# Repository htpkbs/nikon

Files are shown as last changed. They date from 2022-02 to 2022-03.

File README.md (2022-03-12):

# Overview

The nikon is a keyboard PCB.

It has:

* A column-staggered, ortholinear layout
* Low profile Kailh Choc switch spacing
* A split design
* Thumb key clusters
* USB-C
* Symmetry (the same PCB can be used for both left and right halves)

# v1.0 Notes

Capacitors `C1` and `C4` are mislabeled! The silkscreen labels are swapped.

# Key Layout

The key layout looks like this:

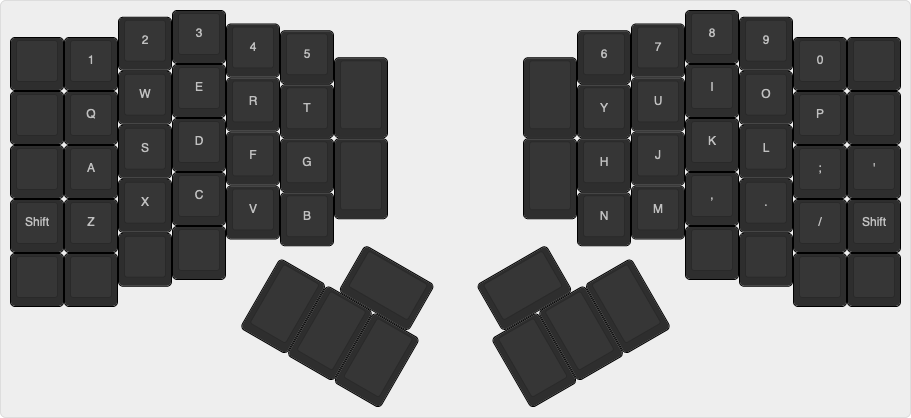
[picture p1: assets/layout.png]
Key layout


This is the raw data that can be pasted into [Keyboard Layout Editor](http://www.keyboard-layout-editor.com/):

```
[{x:3,c:"#2e2e2e",t:"#9c9c9c",a:7},"3",{x:8.5},"8"],
[{y:-0.875,x:2},"2",{x:10.5},"9"],
[{y:-0.875,x:4},"4",{x:6.5},"7"],
[{y:-0.875,x:5},"5",{x:4.5},"6"],
[{y:-0.875},"","1",{x:12.5},"0",""],
[{y:-0.625,x:6,h:1.5},"",{x:2.5,h:1.5},""],
[{y:-0.875,x:3},"E",{x:8.5},"I"],
[{y:-0.875,x:2},"W",{x:10.5},"O"],
[{y:-0.875,x:4},"R",{x:6.5},"U"],
[{y:-0.875,x:5},"T",{x:4.5},"Y"],
[{y:-0.875},"","Q",{x:12.5},"P",""],
[{y:-0.5,x:3},"D",{x:8.5},"K"],
[{y:-0.875,x:2},"S",{x:10.5},"L"],
[{y:-0.875,x:4},"F",{x:6.5},"J"],
[{y:-0.875,x:5},"G",{h:1.5},"",{x:2.5,h:1.5},"","H"],
[{y:-0.875},"","A",{x:12.5},";","'"],
[{y:-0.5,x:3},"C",{x:8.5},","],
[{y:-0.875,x:2},"X",{x:10.5},"."],
[{y:-0.875,x:4},"V",{x:6.5},"M"],
[{y:-0.875,x:5},"B",{x:4.5},"N"],
[{y:-0.875},"Shift","Z",{x:12.5},"/","Shift"],
[{y:-0.375,x:2},"",{x:10.5},""],
[{y:-0.625},"","",{x:12.5},"",""],
[{rx:7.5,ry:4,x:-4.5},""],
[{rx:9,x:3.5},""],
[{r:30,rx:7.5,y:0.75,x:-0.625,w:1.5},""],
[{x:-1.875,h:1.5},"",{h:1.5},"",{h:1.5},""],
[{r:-30,rx:9,y:0.75,x:-0.875,w:1.5},""],
[{x:-1.125,h:1.5},"",{h:1.5},"",{h:1.5},""]
```

# PCB Renders

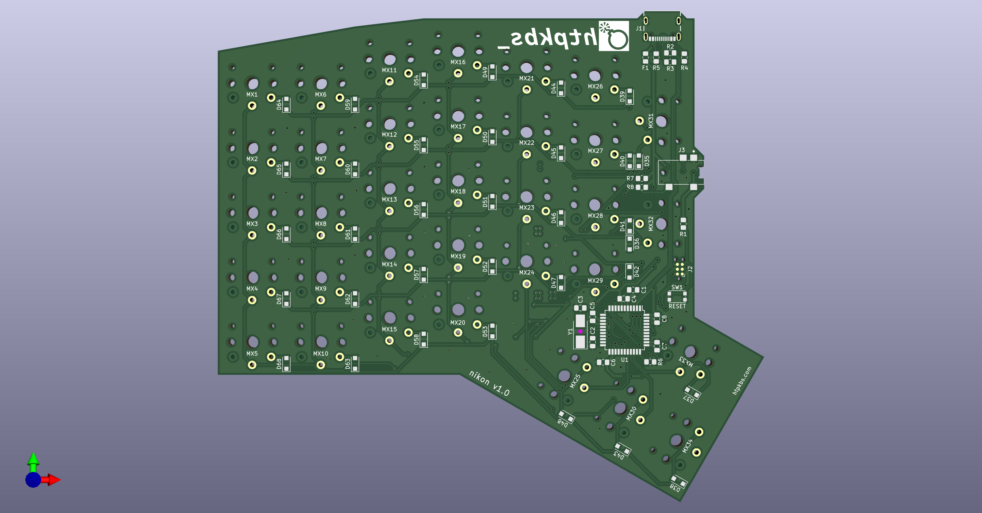
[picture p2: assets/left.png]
Left PCB front


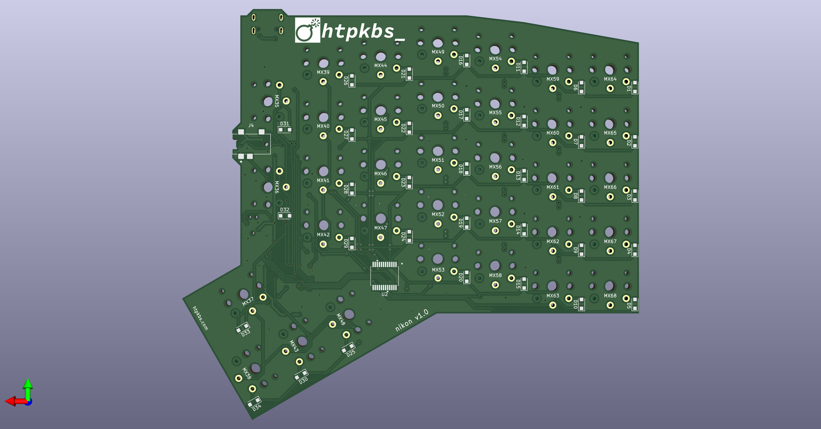
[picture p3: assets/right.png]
Right PCB front


# Case

Files are in the `case` directory.

# Schematic

[There is a PDF of the schematic here](assets/schematic.pdf).

# AVR Programming

To-do.

## QMK

The nikon uses a port expander (the ATmega MCP23018), similar to the ErgoDox. The firmware will likely be copied from the [Pterodactyl keyboard](https://github.com/qmk/qmk_firmware/tree/master/keyboards/handwired/pterodactyl) since that seems to be the most recent keyboard with a custom `matrix.c` and support for a port expander. Eventually hopefully there will be a [generalized matrix.c for keyboards that use I/O expanders](https://github.com/qmk/qmk_firmware/issues/2065).

# Sublicenses

* The Kailh Choc switch footprints are from the [keyswitch-kicad-libary repository](https://github.com/perigoso/keyswitch-kicad-library). [The CC BY 4.0 license is included here](LICENSE.keyswitch-kicad-library).
* The keyswitch symbols are modified versions from the [MX_Alps_Hybrid repository](https://github.com/ai03-2725/MX_Alps_Hybrid). [The MIT license is included here](LICENSE.MX_Alps_Hybrid).
* The TRRS jack symbol and footprint are not licensed by CUI Devices and are free to use.
* The USB jack symbol and footprint are from SnapEDA (linked from the GCT website) and do not appear to be licensed by GCT.
* The MCP23018 symbol and footprint are from Microchip and are subject to the Ultra Library terms and conditions, which state, "You may incorporate the CONTENT that you are authorized to access into your products or designs which may be distributed without restriction, including for commercial, educational, and open-source purposes."

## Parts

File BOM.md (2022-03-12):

# Bill of Materials

J2 (the Tag-Connect ISP headers) and MX1-MX68 (the key switches) are not included.

Since the PCB is reversible, the BOM is split up between the left and right halves. To build a full keyboard, you need the components for both halves.

## Left Half

| Reference | Quantity | Value | Link |
| --- | --- | --- | --- |
| D1-D34 | 34 | 1N4148 | https://www.digikey.com/en/products/detail/taiwan-semiconductor-corporation/1N4148W-RHG/7357065 |
| J4 | 1 | SJ2-35954-SMT-TR | https://www.digikey.com/en/products/detail/cui-devices/SJ2-35954A-SMT-TR/6619576 |
| U2 | 1 | MCP23018-E/SS | https://www.digikey.com/en/products/detail/microchip-technology/MCP23018-E-SS/1999506 |

## Right Half

| Reference | Quantity | Value | Link |
| --- | --- | --- | --- |
| C1 | 1 | 1u | https://www.digikey.com/en/products/detail/avx-corporation/0805DC105KAT2A/11245462 |
| C2, C3 | 2 | 22pF | https://www.digikey.com/en/products/detail/avx-corporation/08055C220JAT2A/1602912 |
| C4 | 1 | 4.7u | https://www.digikey.com/en/products/detail/avx-corporation/08056D475KAT2A/563526 |
| C5-C8 | 4 | 0.1u | https://www.digikey.com/en/products/detail/avx-corporation/08053D104KAT2A/2345252 |
| D35-D68 | 34 | 1N4148 | https://www.digikey.com/en/products/detail/taiwan-semiconductor-corporation/1N4148W-RHG/7357065
| F1 | 1 | 100mA | https://www.digikey.com/en/products/detail/littelfuse-inc/0805L020YR/1212820 |
| J1 | 1 | USB4105-GF-A | https://www.digikey.com/en/products/detail/gct/USB4105-GF-A/11198441 |
| J3 | 1 | SJ2-35954-SMT-TR | https://www.digikey.com/en/products/detail/cui-devices/SJ2-35954A-SMT-TR/6619576 |
| R1, R6 | 2 | 10k | https://www.digikey.com/en/products/detail/bourns-inc/CR0805-FX-1002ELF/3593209 |
| R2, R3 | 2 | 22R | https://www.digikey.com/en/products/detail/bourns-inc/CR0805-FX-22R0ELF/3784764 |
| R4, R5 | 2 | 5.1k | https://www.digikey.com/en/products/detail/bourns-inc/CR0805-FX-5101ELF/3784995 |
| R7, R8 | 2 | 4.7k | https://www.digikey.com/en/products/detail/bourns-inc/CR0805-FX-4701ELF/3784970 |
| SW1 | 1 | Reset | https://www.digikey.com/en/products/detail/c-k/KMR241NG-LFS/2176486 |
| U1 | 1 | ATmega32U4-AU | https://www.digikey.com/en/products/detail/microchip-technology/ATMEGA32U4-AU/1914602 |
| Y1 | 1 | 16MHz | https://www.digikey.com/en/products/detail/abracon-llc/ABM3-16-000MHZ-B2-T/675298 |

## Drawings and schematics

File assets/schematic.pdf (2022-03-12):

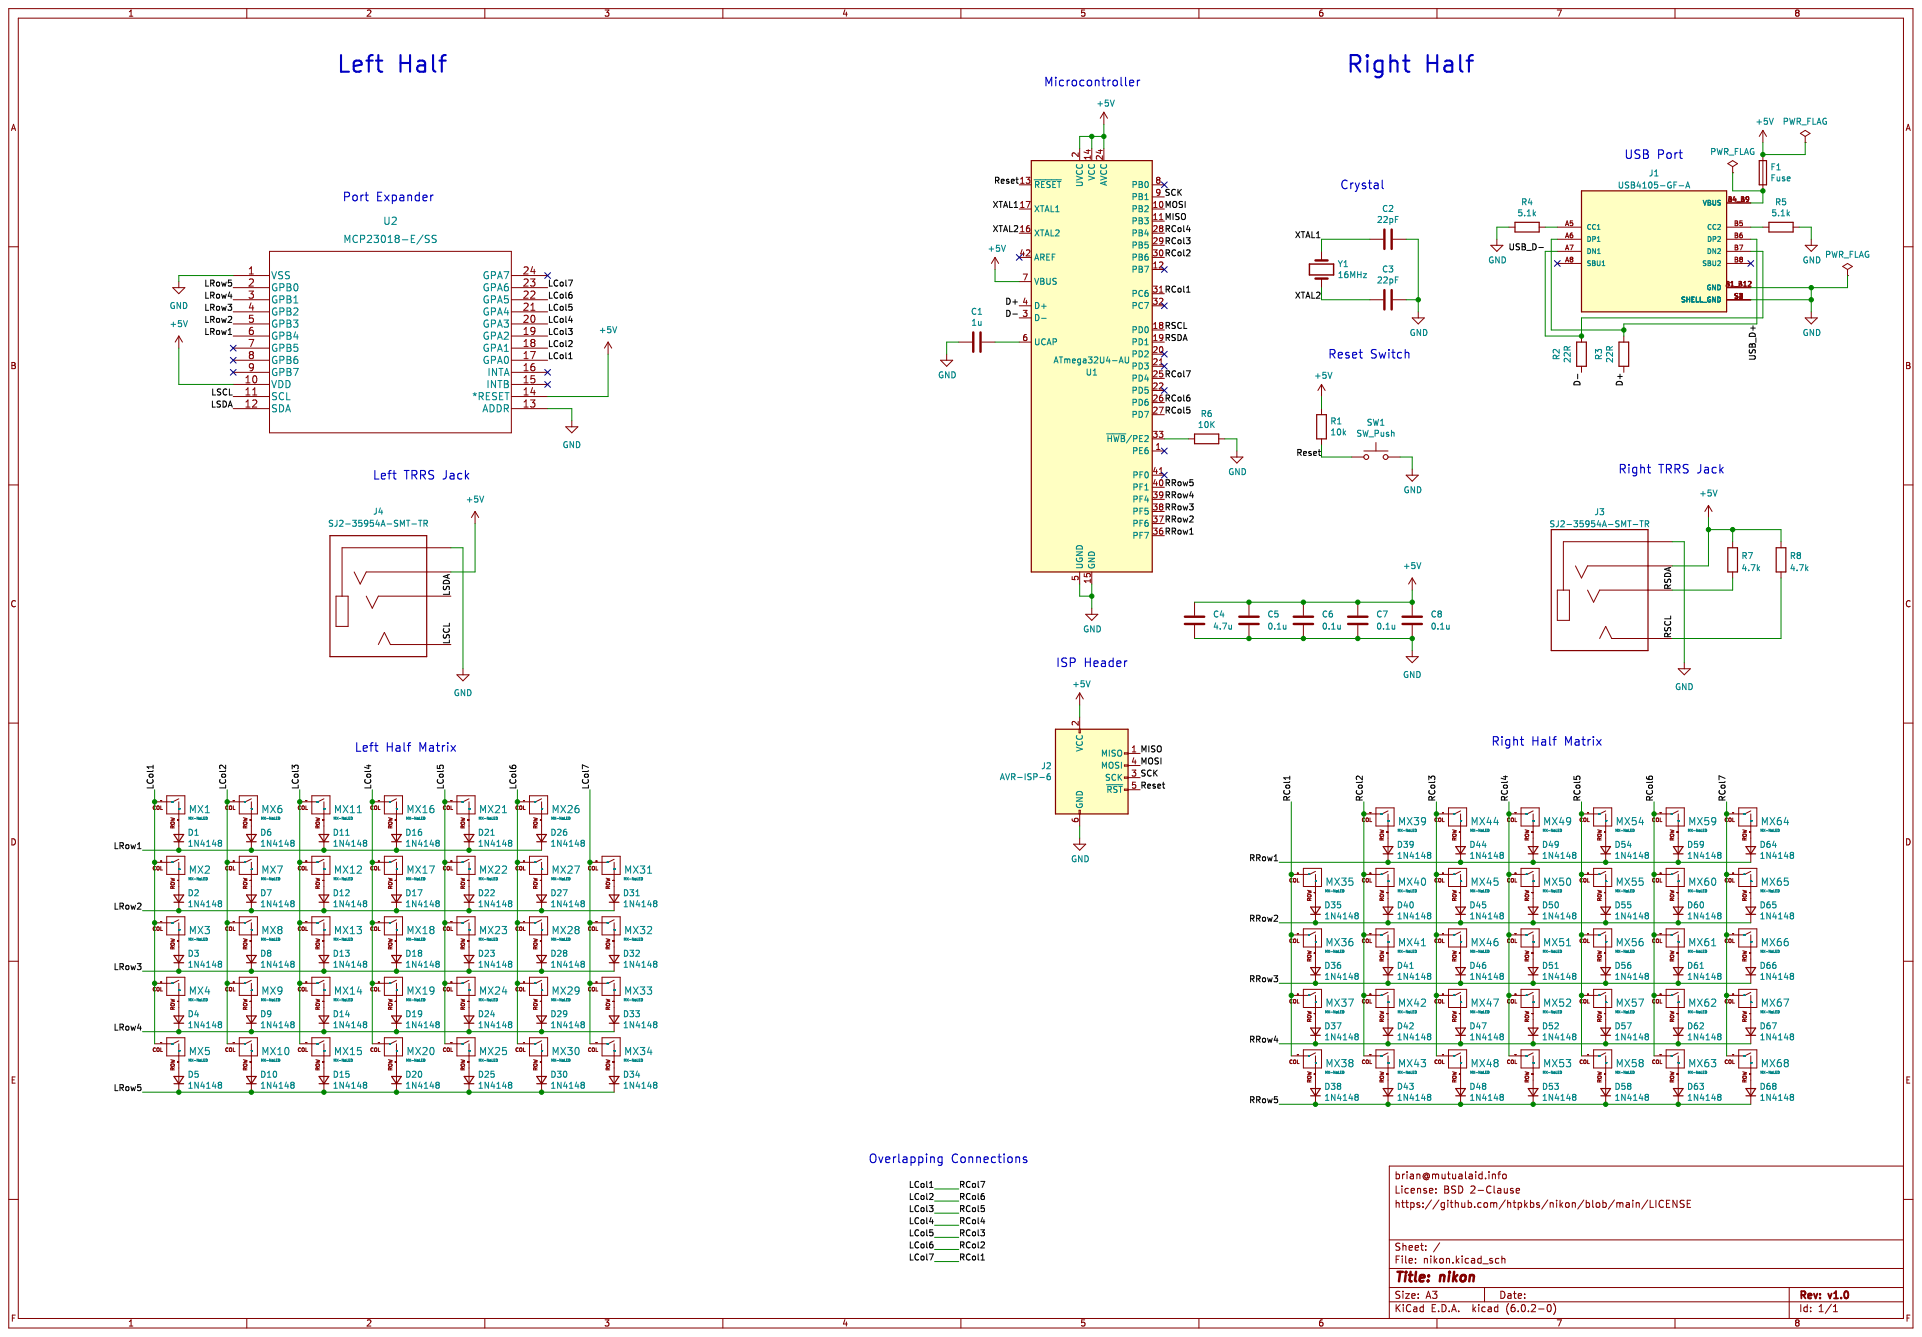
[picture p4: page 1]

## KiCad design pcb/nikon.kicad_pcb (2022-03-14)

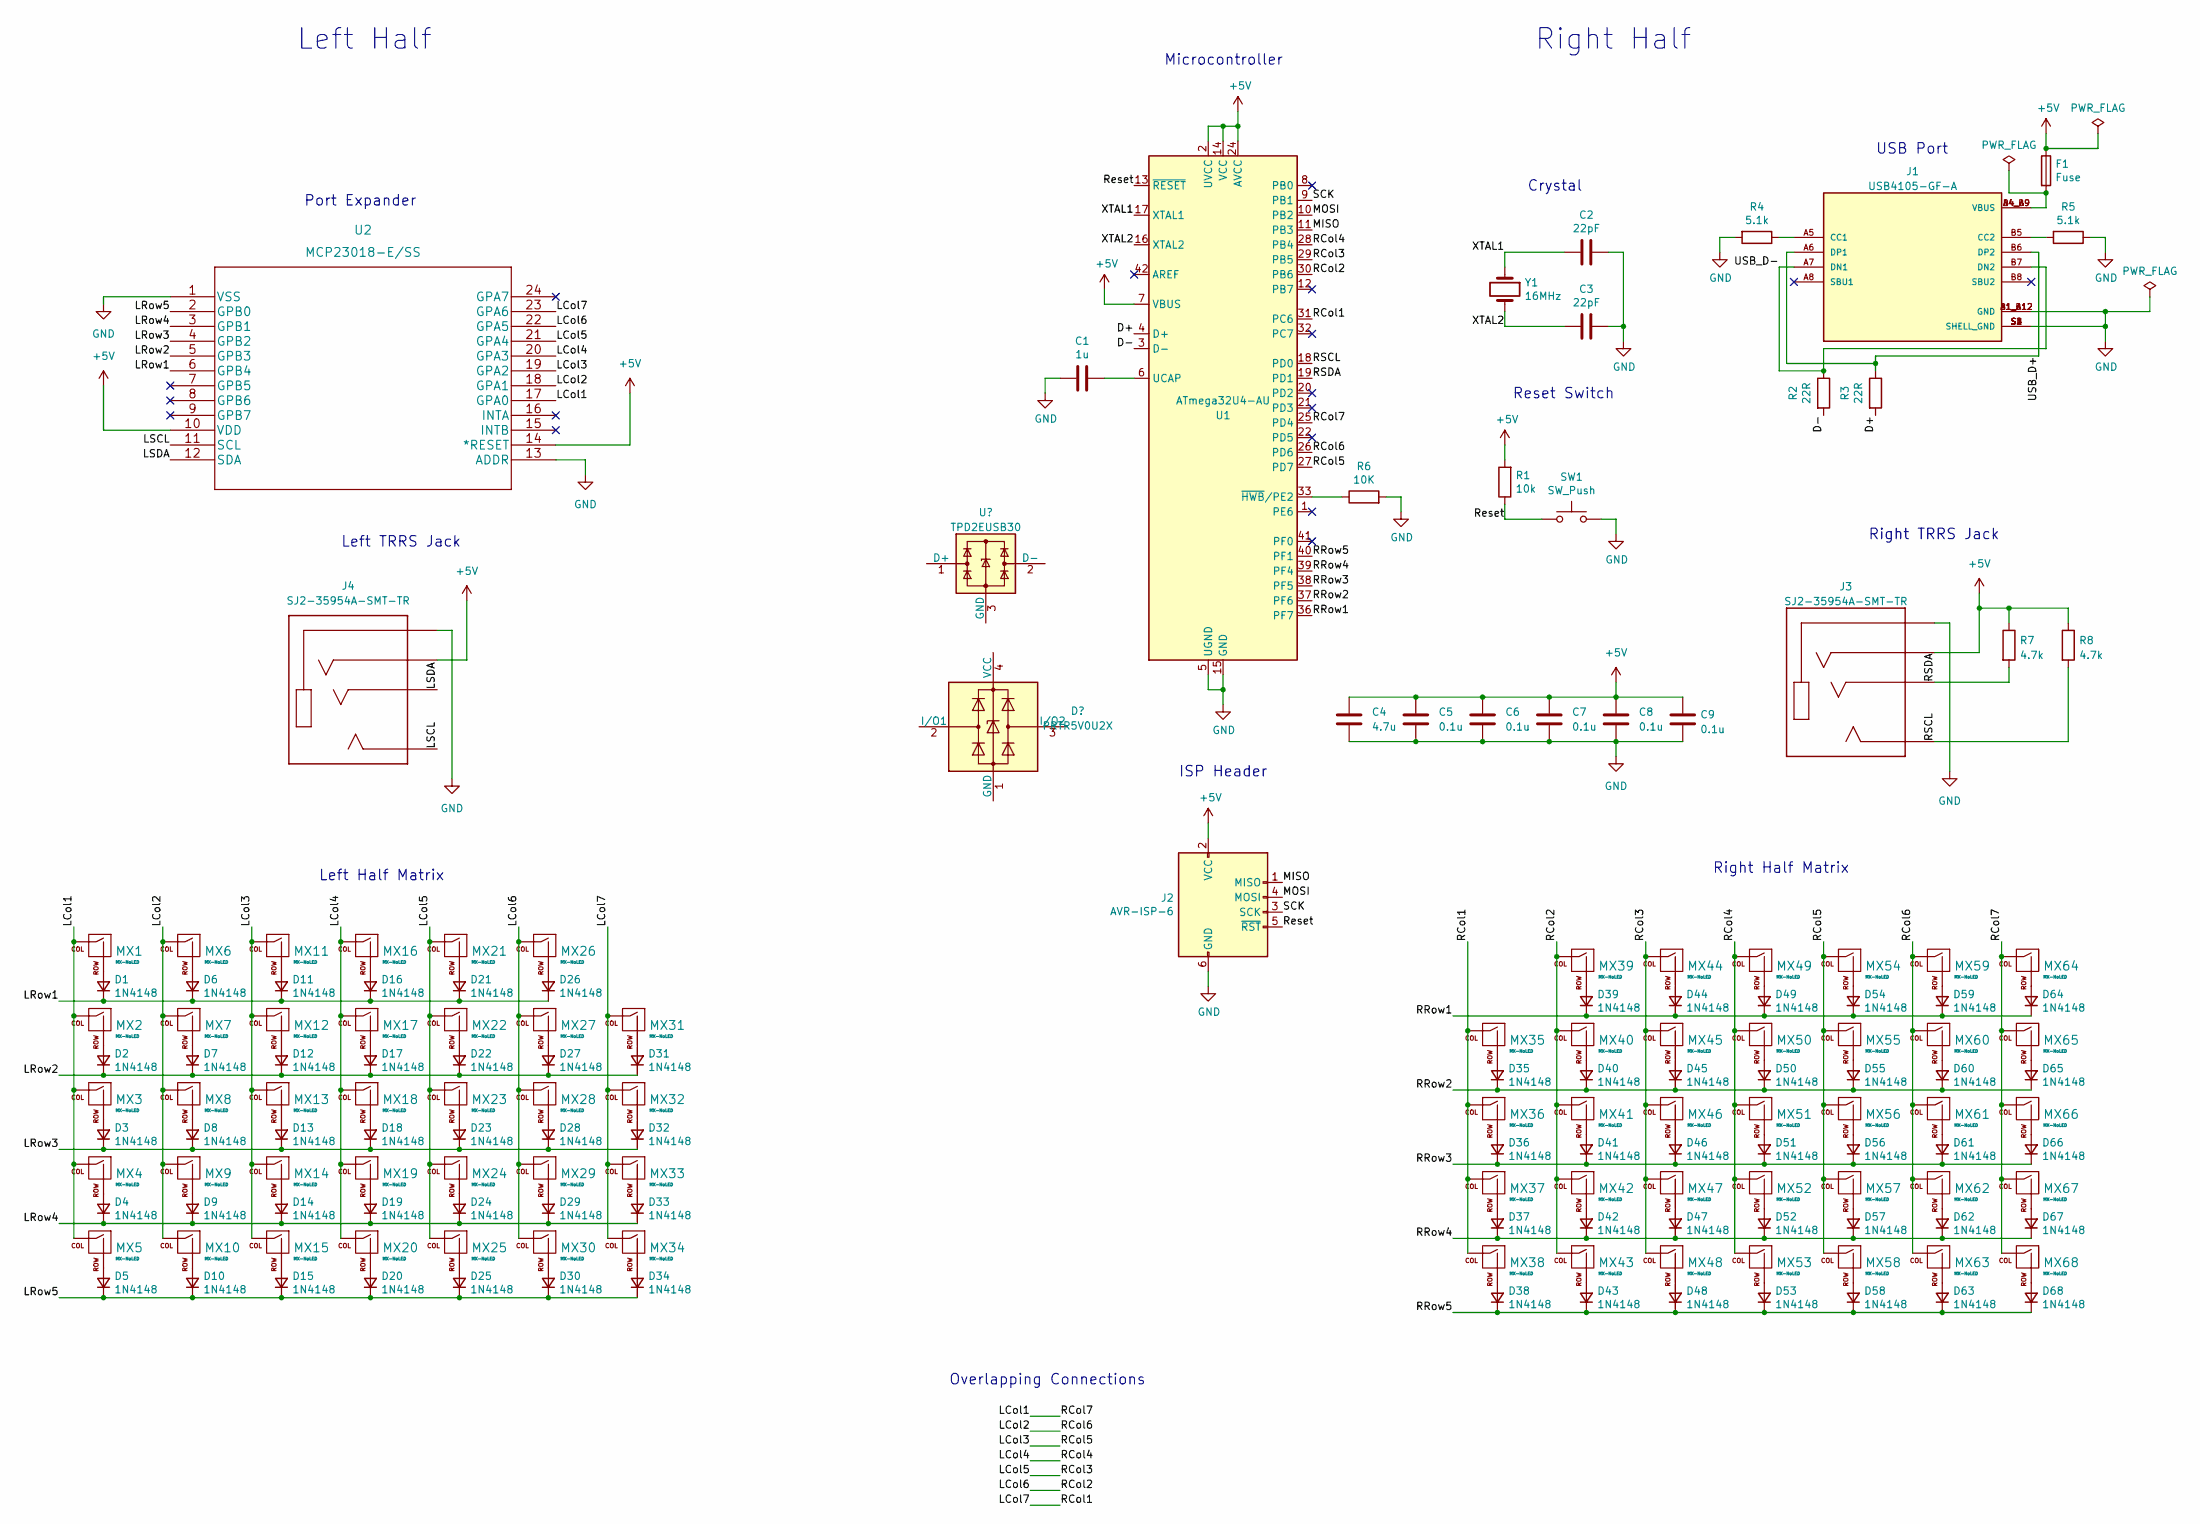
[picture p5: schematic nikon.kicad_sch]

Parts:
C1: 1u; C_0805_2012Metric_Pad1.18x1.45mm_HandSolder
C2, C3: 22pF; C_0805_2012Metric_Pad1.18x1.45mm_HandSolder
C4: 4.7u; C_0805_2012Metric_Pad1.18x1.45mm_HandSolder
C5, C6, C7, C8, C9: 0.1u; C_0805_2012Metric_Pad1.18x1.45mm_HandSolder
D1, D2, D3, D4, D5, D6, D7, D8, D9, D10, D11, D12, D13, D14, D15, D16, D17, D18, D19, D20, D21, D22, D23, D24, D25, D26, D27, D28, D29, D30, D31, D32, D33, D34, D35, D36, D37, D38, D39, D40, D41, D42, D43, D44, D45, D46, D47, D48, D49, D50, D51, D52, D53, D54, D55, D56, D57, D58, D59, D60, D61, D62, D63, D64, D65, D66, D67, D68: 1N4148; D_SOD-123F
F1: Fuse; Fuse_0805_2012Metric_Pad1.15x1.40mm_HandSolder
J1: USB4105-GF-A; GCT_USB4105-GF-A; PARTREV A3
J2: AVR-ISP-6; Tag-Connect_TC2030-IDC-NL_2x03_P1.27mm_Vertical
J3, J4: SJ2-35954A-SMT-TR; CUI_SJ2-35954A-SMT-TR; PARTREV 1.01
MX1, MX2, MX3, MX4, MX5, MX6, MX7, MX8, MX9, MX10, MX11, MX12, MX13, MX14, MX15, MX16, MX17, MX18, MX19, MX20, MX21, MX22, MX23, MX24, MX26, MX27, MX28, MX29, MX39, MX40, MX41, MX42, MX44, MX45, MX46, MX47, MX49, MX50, MX51, MX52, MX53, MX54, MX55, MX56, MX57, MX58, MX59, MX60, MX61, MX62, MX63, MX64, MX65, MX66, MX67, MX68: MX-NoLED; SW_Kailh_Choc_V1_1.00u
MX25, MX30, MX31, MX32, MX33, MX34, MX35, MX36, MX37, MX38, MX43, MX48: MX-NoLED; SW_Kailh_Choc_V1_1.50u
R1: 10k; R_0805_2012Metric_Pad1.20x1.40mm_HandSolder
R2, R3: 22R; R_0805_2012Metric_Pad1.20x1.40mm_HandSolder
R4, R5: 5.1k; R_0805_2012Metric_Pad1.20x1.40mm_HandSolder
R6: 10K; R_0805_2012Metric_Pad1.20x1.40mm_HandSolder
R7, R8: 4.7k; R_0805_2012Metric_Pad1.20x1.40mm_HandSolder
SW1: SW_Push; SW_Push_1P1T_NO_CK_KMR2
U1: ATmega32U4-AU; TQFP-44_10x10mm_P0.8mm
U2: MCP23018-E/SS; MCP23018-E&slash_SS
Y1: 16MHz; Crystal_SMD_Abracon_ABM3-2Pin_5.0x3.2mm_HandSoldering

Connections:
+5V: C4.1, C5.1, C6.1, C7.1, C8.1, C9.1, F1.1, J2.2 (VCC), J3.4, J4.4, R1.2, R7.1, R8.1, U1.2 (UVCC), U1.7 (VBUS), U1.14 (VCC), U1.24 (AVCC), U1.34 (VCC), U1.44 (AVCC), U2.10 (VDD), U2.14 (*RESET)
/D+: R3.2, U1.4 (D+)
/D-: R2.2, U1.3 (D-)
/LCol1: MX1.1 (COL), MX2.1 (COL), MX3.1 (COL), MX4.1 (COL), MX5.1 (COL), MX64.1 (COL), MX65.1 (COL), MX66.1 (COL), MX67.1 (COL), MX68.1 (COL), U1.25 (PD4), U2.17 (GPA0)
/LCol2: MX6.1 (COL), MX7.1 (COL), MX8.1 (COL), MX9.1 (COL), MX10.1 (COL), MX59.1 (COL), MX60.1 (COL), MX61.1 (COL), MX62.1 (COL), MX63.1 (COL), U1.26 (PD6), U2.18 (GPA1)
/LCol3: MX11.1 (COL), MX12.1 (COL), MX13.1 (COL), MX14.1 (COL), MX15.1 (COL), MX54.1 (COL), MX55.1 (COL), MX56.1 (COL), MX57.1 (COL), MX58.1 (COL), U1.27 (PD7), U2.19 (GPA2)
/LCol4: MX16.1 (COL), MX17.1 (COL), MX18.1 (COL), MX19.1 (COL), MX20.1 (COL), MX49.1 (COL), MX50.1 (COL), MX51.1 (COL), MX52.1 (COL), MX53.1 (COL), U1.28 (PB4), U2.20 (GPA3)
/LCol5: MX21.1 (COL), MX22.1 (COL), MX23.1 (COL), MX24.1 (COL), MX25.1 (COL), MX44.1 (COL), MX45.1 (COL), MX46.1 (COL), MX47.1 (COL), MX48.1 (COL), U1.29 (PB5), U2.21 (GPA4)
/LCol6: MX26.1 (COL), MX27.1 (COL), MX28.1 (COL), MX29.1 (COL), MX30.1 (COL), MX39.1 (COL), MX40.1 (COL), MX41.1 (COL), MX42.1 (COL), MX43.1 (COL), U1.30 (PB6), U2.22 (GPA5)
/LCol7: MX31.1 (COL), MX32.1 (COL), MX33.1 (COL), MX34.1 (COL), MX35.1 (COL), MX36.1 (COL), MX37.1 (COL), MX38.1 (COL), U1.31 (PC6), U2.23 (GPA6)
/LRow1: D1.1 (K), D6.1 (K), D11.1 (K), D16.1 (K), D21.1 (K), D26.1 (K), U2.6 (GPB4)
/LRow2: D2.1 (K), D7.1 (K), D12.1 (K), D17.1 (K), D22.1 (K), D27.1 (K), D31.1 (K), U2.5 (GPB3)
/LRow3: D3.1 (K), D8.1 (K), D13.1 (K), D18.1 (K), D23.1 (K), D28.1 (K), D32.1 (K), U2.4 (GPB2)
/LRow4: D4.1 (K), D9.1 (K), D14.1 (K), D19.1 (K), D24.1 (K), D29.1 (K), D33.1 (K), U2.3 (GPB1)
/LRow5: D5.1 (K), D10.1 (K), D15.1 (K), D20.1 (K), D25.1 (K), D30.1 (K), D34.1 (K), U2.2 (GPB0)
/LSCL: J4.2, U2.11 (SCL)
/LSDA: J4.3, U2.12 (SDA)
/MISO: J2.1 (MISO), U1.11 (PB3)
/MOSI: J2.4 (MOSI), U1.10 (PB2)
/RRow1: D39.1 (K), D44.1 (K), D49.1 (K), D54.1 (K), D59.1 (K), D64.1 (K), U1.36 (PF7)
/RRow2: D35.1 (K), D40.1 (K), D45.1 (K), D50.1 (K), D55.1 (K), D60.1 (K), D65.1 (K), U1.37 (PF6)
/RRow3: D36.1 (K), D41.1 (K), D46.1 (K), D51.1 (K), D56.1 (K), D61.1 (K), D66.1 (K), U1.38 (PF5)
/RRow4: D37.1 (K), D42.1 (K), D47.1 (K), D52.1 (K), D57.1 (K), D62.1 (K), D67.1 (K), U1.39 (PF4)
/RRow5: D38.1 (K), D43.1 (K), D48.1 (K), D53.1 (K), D58.1 (K), D63.1 (K), D68.1 (K), U1.40 (PF1)
/RSCL: J3.2, R8.2, U1.18 (PD0)
/RSDA: J3.3, R7.2, U1.19 (PD1)
/Reset: J2.5 (~RST), R1.1, SW1.1, U1.13 (~RESET)
/SCK: J2.3 (SCK), U1.9 (PB1)
/USB_D+: J1.A6 (DP1), J1.B6 (DP2), R3.1
/USB_D-: J1.A7 (DN1), J1.B7 (DN2), R2.1
/XTAL1: C2.2, U1.17 (XTAL1), Y1.1
/XTAL2: C3.2, U1.16 (XTAL2), Y1.2
GND: C1.2, C2.1, C3.1, C4.2, C5.2, C6.2, C7.2, C8.2, C9.2, J1.A1_B12 (GND), J1.B1_A12 (GND), J1.S1 (SHELL_GND), J1.S2 (SHELL_GND), J1.S3 (SHELL_GND), J1.S4 (SHELL_GND), J2.6 (GND), J3.1, J4.1, R4.2, R5.1, R6.2, SW1.2, U1.5 (UGND), U1.15 (GND), U1.23 (GND), U1.35 (GND), U1.43 (GND), U2.1 (VSS), U2.13 (ADDR)
unnamed: C1.1, U1.6 (UCAP)
unnamed: D1.2 (A), MX1.2 (ROW)
unnamed: D2.2 (A), MX2.2 (ROW)
unnamed: D3.2 (A), MX3.2 (ROW)
unnamed: D4.2 (A), MX4.2 (ROW)
unnamed: D5.2 (A), MX5.2 (ROW)
unnamed: D6.2 (A), MX6.2 (ROW)
unnamed: D7.2 (A), MX7.2 (ROW)
unnamed: D8.2 (A), MX8.2 (ROW)
unnamed: D9.2 (A), MX9.2 (ROW)
unnamed: D10.2 (A), MX10.2 (ROW)
unnamed: D11.2 (A), MX11.2 (ROW)
unnamed: D12.2 (A), MX12.2 (ROW)
unnamed: D13.2 (A), MX13.2 (ROW)
unnamed: D14.2 (A), MX14.2 (ROW)
unnamed: D15.2 (A), MX15.2 (ROW)
unnamed: D16.2 (A), MX16.2 (ROW)
unnamed: D17.2 (A), MX17.2 (ROW)
unnamed: D18.2 (A), MX18.2 (ROW)
unnamed: D19.2 (A), MX19.2 (ROW)
unnamed: D20.2 (A), MX20.2 (ROW)
unnamed: D21.2 (A), MX21.2 (ROW)
unnamed: D22.2 (A), MX22.2 (ROW)
unnamed: D23.2 (A), MX23.2 (ROW)
unnamed: D24.2 (A), MX24.2 (ROW)
unnamed: D25.2 (A), MX25.2 (ROW)
unnamed: D26.2 (A), MX26.2 (ROW)
unnamed: D27.2 (A), MX27.2 (ROW)
unnamed: D28.2 (A), MX28.2 (ROW)
unnamed: D29.2 (A), MX29.2 (ROW)
unnamed: D30.2 (A), MX30.2 (ROW)
unnamed: D31.2 (A), MX31.2 (ROW)
unnamed: D32.2 (A), MX32.2 (ROW)
unnamed: D33.2 (A), MX33.2 (ROW)
unnamed: D34.2 (A), MX34.2 (ROW)
unnamed: D35.2 (A), MX35.2 (ROW)
unnamed: D36.2 (A), MX36.2 (ROW)
unnamed: D37.2 (A), MX37.2 (ROW)
unnamed: D38.2 (A), MX38.2 (ROW)
unnamed: D39.2 (A), MX39.2 (ROW)
unnamed: D40.2 (A), MX40.2 (ROW)
unnamed: D41.2 (A), MX41.2 (ROW)
unnamed: D42.2 (A), MX42.2 (ROW)
unnamed: D43.2 (A), MX43.2 (ROW)
unnamed: D44.2 (A), MX44.2 (ROW)
unnamed: D45.2 (A), MX45.2 (ROW)
unnamed: D46.2 (A), MX46.2 (ROW)
unnamed: D47.2 (A), MX47.2 (ROW)
unnamed: D48.2 (A), MX48.2 (ROW)
unnamed: D49.2 (A), MX49.2 (ROW)
unnamed: D50.2 (A), MX50.2 (ROW)
unnamed: D51.2 (A), MX51.2 (ROW)
unnamed: D52.2 (A), MX52.2 (ROW)
unnamed: D53.2 (A), MX53.2 (ROW)
unnamed: D54.2 (A), MX54.2 (ROW)
unnamed: D55.2 (A), MX55.2 (ROW)
unnamed: D56.2 (A), MX56.2 (ROW)
unnamed: D57.2 (A), MX57.2 (ROW)
unnamed: D58.2 (A), MX58.2 (ROW)
unnamed: D59.2 (A), MX59.2 (ROW)
unnamed: D60.2 (A), MX60.2 (ROW)
unnamed: D61.2 (A), MX61.2 (ROW)
unnamed: D62.2 (A), MX62.2 (ROW)
unnamed: D63.2 (A), MX63.2 (ROW)
unnamed: D64.2 (A), MX64.2 (ROW)
unnamed: D65.2 (A), MX65.2 (ROW)
unnamed: D66.2 (A), MX66.2 (ROW)
unnamed: D67.2 (A), MX67.2 (ROW)
unnamed: D68.2 (A), MX68.2 (ROW)
unnamed: F1.2, J1.A4_B9 (VBUS), J1.B4_A9 (VBUS)
unnamed: J1.A5 (CC1), R4.1
unnamed: J1.B5 (CC2), R5.2
unnamed: R6.1, U1.33 (~HWB/PE2)

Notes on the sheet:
Left TRRS Jack
Reset Switch
Right TRRS Jack
Left Half
Right Half
Microcontroller
Overlapping Connections
Crystal
Port Expander
Left Half Matrix
ISP Header
Right Half Matrix
USB Port

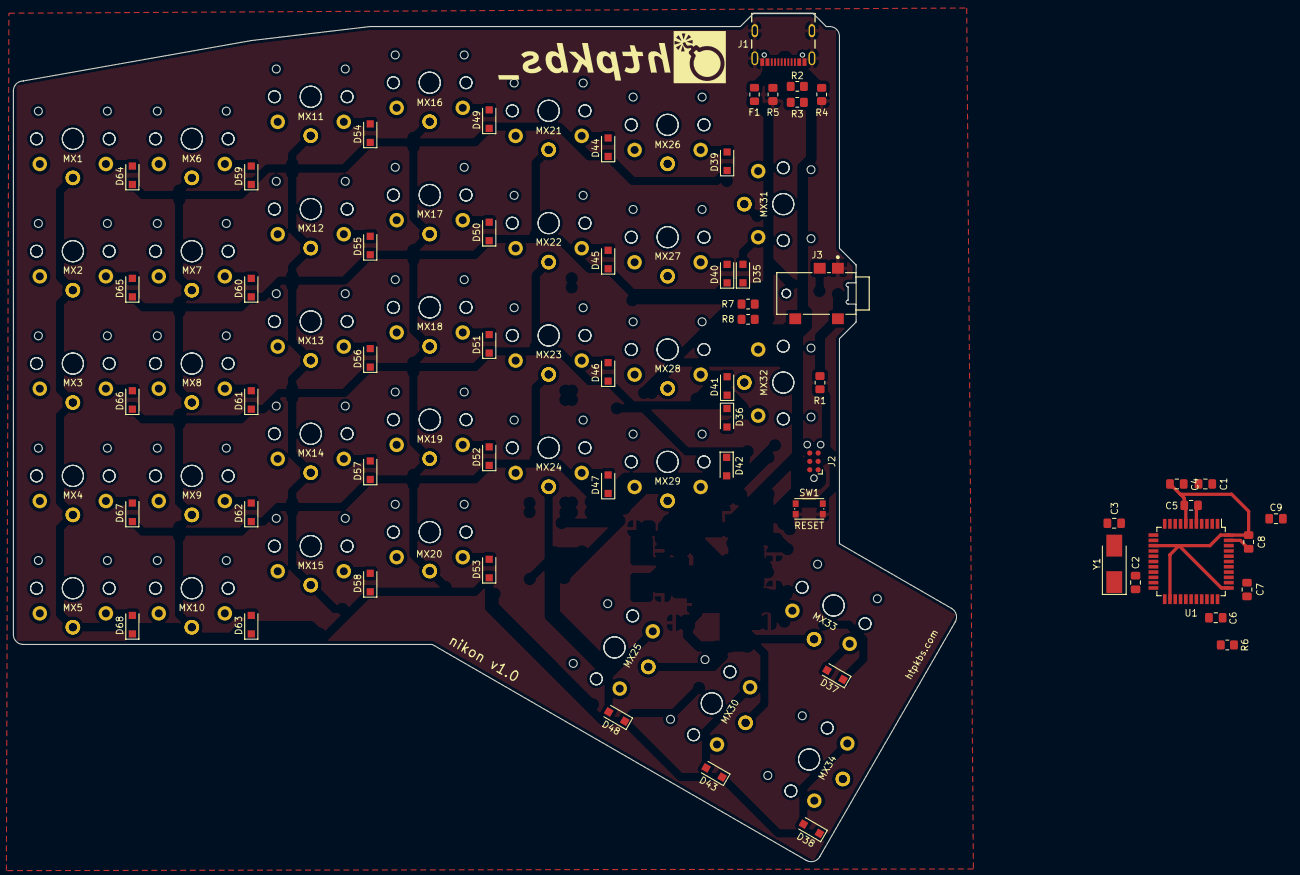
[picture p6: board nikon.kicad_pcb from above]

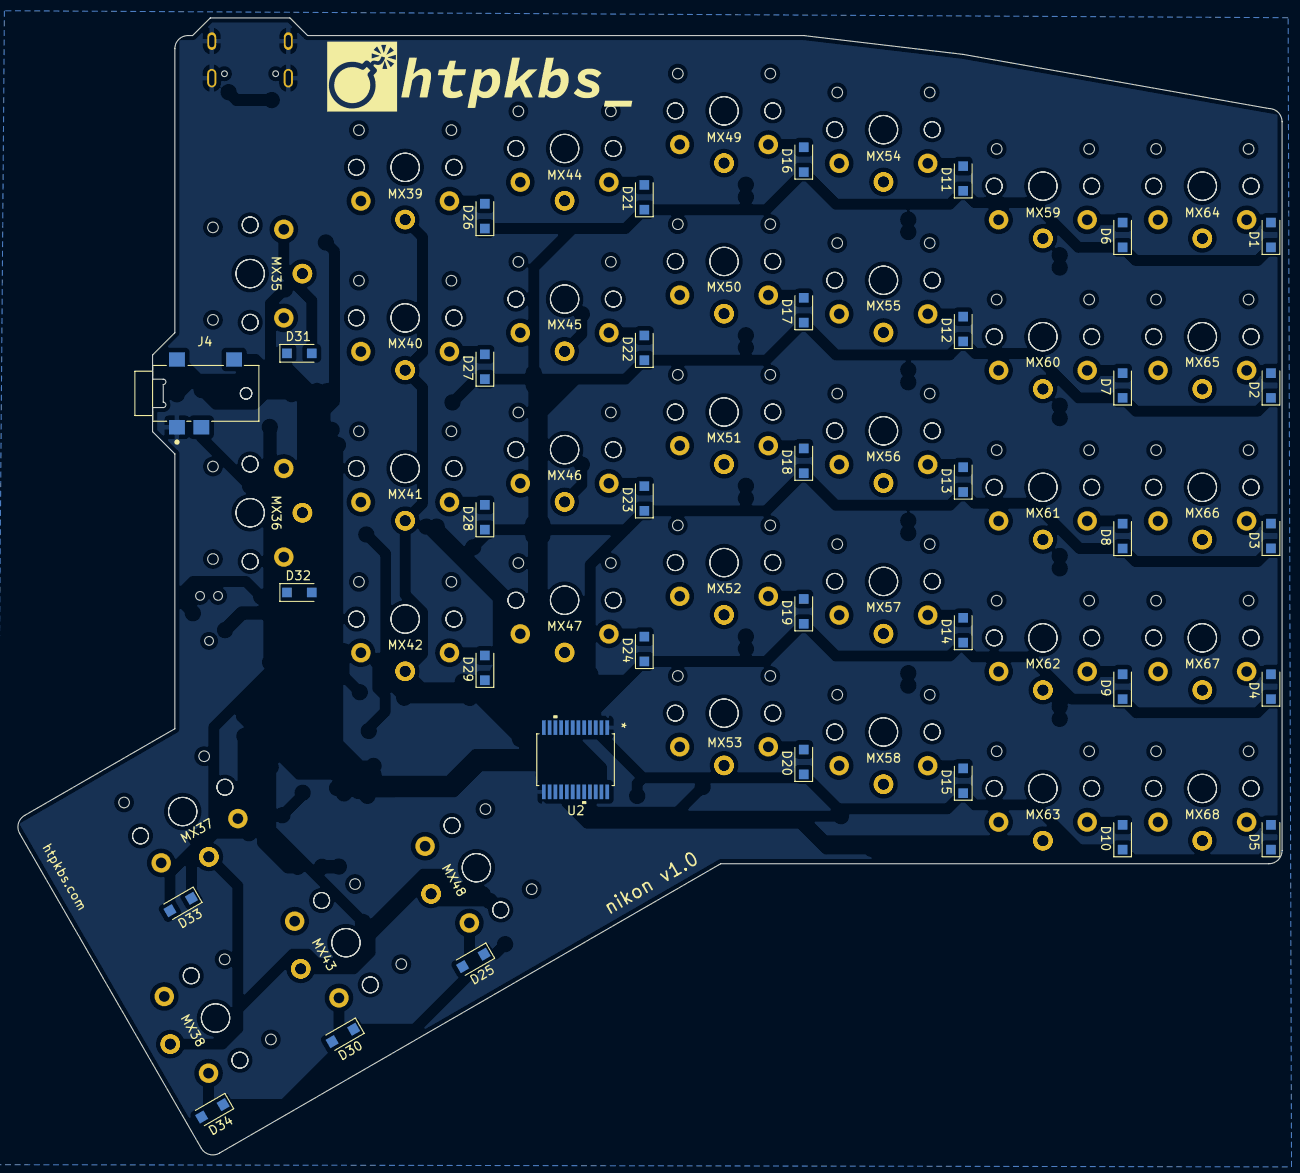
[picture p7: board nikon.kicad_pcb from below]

Board: 2 copper layers, 142.7 x 128.4 mm, 162 parts (70 on the bottom side), 106 nets.

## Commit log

2022-02-28 both halves
    [nikon.kicad_pcb, nikon.kicad_sch, nikon.sch]
2022-03-12 remove right pcb
    [nikon.kicad_pcb, nikon.kicad_sch, nikon.sch]
2022-03-12 add bom

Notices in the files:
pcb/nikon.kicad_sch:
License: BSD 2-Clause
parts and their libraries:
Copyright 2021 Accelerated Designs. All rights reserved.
